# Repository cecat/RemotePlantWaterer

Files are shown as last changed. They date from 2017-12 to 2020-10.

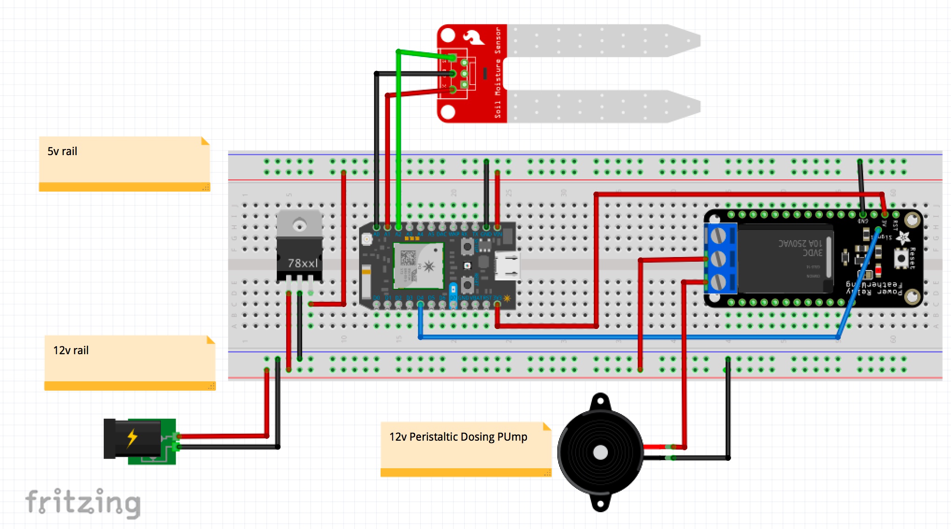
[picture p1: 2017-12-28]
hardware/breadboard.jpeg

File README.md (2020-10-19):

# RemotePlantWaterer

This is a very simple plant watering system that takes advantage of the Particle Photon and
Particle's cloud service that can be connected to (e.g.) IFTTT. You could readily put a
button on it or other controls, but this project assumes you're going to issue commands
via the Particle integration with IFTTT (and thus you're reasonably familiar with
Particle integrations and IFTTT).

## Hardware
I use a Particle Photon and a
[12v peristaltic dosing pump](https://www.amazon.com/Kamoer-Peristaltic-Hydroponics-Nutrient-Analytical/dp/B07GWJ78FN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)

Power it with a 12v >=1A DC power supply, e.g. with 5.5mm x 2.1mm (10mm long) connector and socket
like [this](https://www.amazon.com/QTEATAK-Adapter-Connector-Dustproof-Waterproof/dp/B07VTZX2RK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).

The pump is controlled with a FeatherWing non-latching mini-relay which is a bit overkill ($8).
In my 3rd device I switched to an H-Bridge (motor driver), which is $2-3 and smaller
(the FeatherWing is bigger than the Photon, so makes things a bit tight in the box).

## Particle & IFTTT Notes
Copy and paste the source code into a sketch in the Particle IDE.  Make sure to search for
and include the libraries that correspond to the #include files (Particle IDE will duplicate
the #include lines, so after you do the linking you can remove the dupes)

On IFTTT you will link to your Particle account. Here for instance you can create an
applet where THIS is a time of day (select date/time, daily at noon) and for the "THAT" you
select Particle "Call a function."  Here you will see your photon (if it is running) and
the parse function, e.g. if your photon is named "rainmaker" then you will select "parse"
on "rainmaker"" with input "ON"

## Practical Stuff

The particle sketch is set up so that the pump will automatically turn itself off after
900000ms (15 min).  If you want a different default runTime just set it here and then flash your photon.

If you slightly bend the terminals at the back of the pump it will fit very nicely into a
project box like
[this](https://www.amazon.com/Awclub-Waterproof-Dustproof-Transparent-100mmx68mmx50mm/dp/B07C9BBH7G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).
With a dremel or equiv you need to cut a hole in the box lid to slide the pump in up to
its collar.  You'll also need to drill a hole in the side for your power plug.

The pump has short in/out tubes attached, which nicely slide into standard aquarium air
pump tubing. You may want to buy some connectors in case you want to extend or split via
T-connectors. To water an area, such as a planter box, you can cap the tube and use a
small nail to poke holes through every inch or two, creating a soaker hose.

Depending on how hard your water is these will start to plug up after a few weeks, and the
pump is very strong so it will either pop your end cap out (however you closed the end of
the tube) or it will pop the whole tube off at the pump.  Unfortunately this pump is not
quite hefty enough to drive the common Rainbird type watering systems.  But one could use
this system to power a solenoid rather than a pump if you wanted to use a standard water supply...

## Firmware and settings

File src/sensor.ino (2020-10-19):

//
// simple pump              - CeC 7/15/17
// add moisture sensor      - CeC 7/23/17
//

// behavior configuration
//
#define runTime 900000      // ms to run (15min = 900,000)
#define brief   300000      // for a brief run (5 min = 300,000)
// bone dry is about 4000 ; soaked is about 1200
#define DRY     2400        // kinda dry

// hardware configuration
//
#define pumpPin D4          // put pump (relay) control on D4 

// water sensor using A pins for power/ground to turn on/off only 
// when needed (otherwise the probes and soil act like a battery and they erode)
#define h2oGND  A0          // GND on pin A0
#define h2oVCC  A1          // VCC on pin A1
#define h2oDAT  A2          // Analog data on pin A2

// Other Vars and setup
//
int state       = 0;        // pump state
int howLong     = 0;        // int to hold the ad hoc request to run for xxx ms
int msPump      = 0;        // how much time have we been pumping, roughly, updated every 10s
int moisture    = 0;
bool thirsty    = TRUE;     // is it dry? checked every minute in housekeep

// Timers
//
Timer pumpTimer(runTime, finito);   // turn it off after runTime (#defined above) ms
Timer hkeeper(20000, housekeep);    // housekeeping stuff every 20s

// Setup
//
void setup() {
    Particle.function("parse", parse);
    Particle.variable("state", state);          //NOTE - if you use a cellular-connected
    Particle.variable("msPump", msPump);        // Particle Electron don't use variables
    Particle.variable("moisture", moisture);    // because they burn through your data ($$)
    Particle.variable("thirsty", thirsty);
    pinMode(pumpPin, OUTPUT);
    pinMode(h2oGND, OUTPUT);
    pinMode(h2oVCC, OUTPUT);
    pinMode(h2oDAT, INPUT);
    digitalWrite(h2oGND, LOW);      // GND for h2o sensor
    hkeeper.start();                // start the houskeeping task running every minute
    delay (5000);                   // give the moisture sensor time to fire up
    moisture = analogRead(h2oDAT);
}

void loop() {
    // everything is interrupt- or timer-driven
}

// parse is called via IFTTT
//
int parse(String cmd) {
    cmd.trim();
    cmd.toUpperCase();
    
    if (cmd.startsWith("ON") && thirsty) { // turn the relay ON if soil is dry
        digitalWrite(pumpPin, HIGH);
        state = 1;
        pumpTimer.start();
        msPump = 0;
    }
    
    if (cmd.startsWith("OF")) { // "OFF" - turn the relay OFF
        finito();
    }

    if (cmd.startsWith("FO")) { // "FORCE" - turn the relay on, ignoring moisture sensor
        digitalWrite(pumpPin, HIGH);
        state = 1;
        pumpTimer.start();
        msPump = 0;
    }
}

void finito() {
    digitalWrite(pumpPin, LOW);
    msPump = 0;
    state = 0;
}

void housekeep() {
    
    // monitor moisture
    // turn on the sensor (keep it off most of the time 
	// as it aspires to be a battery and will erode the probes)
    digitalWrite(h2oVCC, HIGH);     // VCC for h2o sensor
    delay(1000);
    moisture = analogRead(h2oDAT);
    digitalWrite(h2oVCC, LOW);      // turn off VCC while not in use
    
    thirsty = (moisture > DRY);

    // keep track of how long we have run so we can report for the curious
    if (state) {
        msPump++;
    } else {
        msPump = 0;
    }
}

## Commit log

2017-12-28 more hdwr detail
    [simple-ifttt-pumper.fzz]
2017-12-28 Delete simple-ifttt-pumper.fzz
    moved to hardware directory
    [simple-ifttt-pumper.fzz]
2017-12-28 picture ~= 1k words
    [simple-ifttt-pumper.fzz]
